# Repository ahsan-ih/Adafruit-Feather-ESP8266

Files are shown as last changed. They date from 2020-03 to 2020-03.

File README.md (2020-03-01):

## Adafruit Feather HUZZAH with ESP8266 - Loose Headers PCB

**DISCLAIMER:**: The original creators of the Adafruit Feather HUZZAH with ESP8266 are [Adafruit.com](https://www.adafruit.com). The development has been presented in the given repository just for demonstration purposes.

PCB files for the Adafruit Feather HUZZAH with ESP8266 - Loose Headers. Format is EagleCAD schematic and board layout

- https://www.adafruit.com/product/2821

### Description

Feather is the new development board from Adafruit, and like its namesake it is thin, light, and lets you fly! We designed Feather to be a new standard for portable microcontroller cores.

This is the **Adafruit Feather HUZZAH ESP8266** - our take on an 'all-in-one' ESP8266 WiFi development board with built in USB and battery charging. Its an ESP8266 WiFi module with all the extras you need, ready to rock! [We have other boards in the Feather family, check'em out here.](https://www.adafruit.com/feather)

At the Feather HUZZAH's heart is an ESP8266 WiFi microcontroller clocked at 80 MHz and at 3.3V logic. This microcontroller contains a Tensilica chip core as well as a full WiFi stack. You can program the microcontroller using the Arduino IDE for an easy-to-run Internet of Things core. We wired up a high-quality SiLabs CP2104 USB-Serial chip that can upload code at a blistering 921600 baud for fast development time. It also has auto-reset so no noodling with pins and reset button pressings. The CP2104 has better driver support than the CH340 and can do very high speeds without stability issues.

To make it easy to use for portable projects, we added a connector for any of our 3.7V Lithium polymer batteries and built in battery charging. You don't need a battery, it will run just fine straight from the micro USB connector. But, if you do have a battery, you can take it on the go, then plug in the USB to recharge. The Feather will automatically switch over to USB power when its available.

**Here's some handy specs!**

- Measures 2.0" x 0.9" x 0.28" (51mm x 23mm x 8mm) without headers soldered in
- Light as a (large?) feather - 9.7 grams
- ESP8266 @ 80MHz with 3.3V logic/power
- 4MB of FLASH (32 MBit)
- Built in WiFi 802.11 b/g/n
- 3.3V regulator with 500mA peak current output
- CP2104 USB-Serial converter onboard with 921600 max baudrate for speedy uploading
- Auto-reset support for getting into bootload mode before firmware upload
- 9 x GPIO pins - can also be used as I2C and SPI
- 1 x analog inputs 1.0V max
- Built in 100mA LiPoly charger with charging status indicator LED, can also cut a trace to disable the charger
- Pin #0 red LED for general purpose blinking. Pin #2 blue LED for bootloading debug & general purpose blinking
- Power/enable pin
- 4 mounting holes
- Reset button
  Comes fully assembled and tested, with a USB interface that lets you quickly use it with the Arduino IDE or NodeMCU Lua (it comes preprogrammed with the Lua interpreter). We also toss in some headers so you can solder it in and plug into a solderless breadboard. **Lipoly battery and USB cable not included** (but we do have lots of options in the shop if you'd like!)

[Check out our tutorial for all sorts of details, including schematics, files, IDE instructions, power management and more!](https://learn.adafruit.com/adafruit-feather-huzzah-esp8266)

### License

Adafruit invests time and resources providing this open source design, please support Adafruit and open-source hardware by purchasing products from [Adafruit](https://www.adafruit.com)!

Designed by Limor Fried/Ladyada for Adafruit Industries.

Creative Commons Attribution/Share-Alike, all text above must be included in any redistribution. See license.txt for additional details.

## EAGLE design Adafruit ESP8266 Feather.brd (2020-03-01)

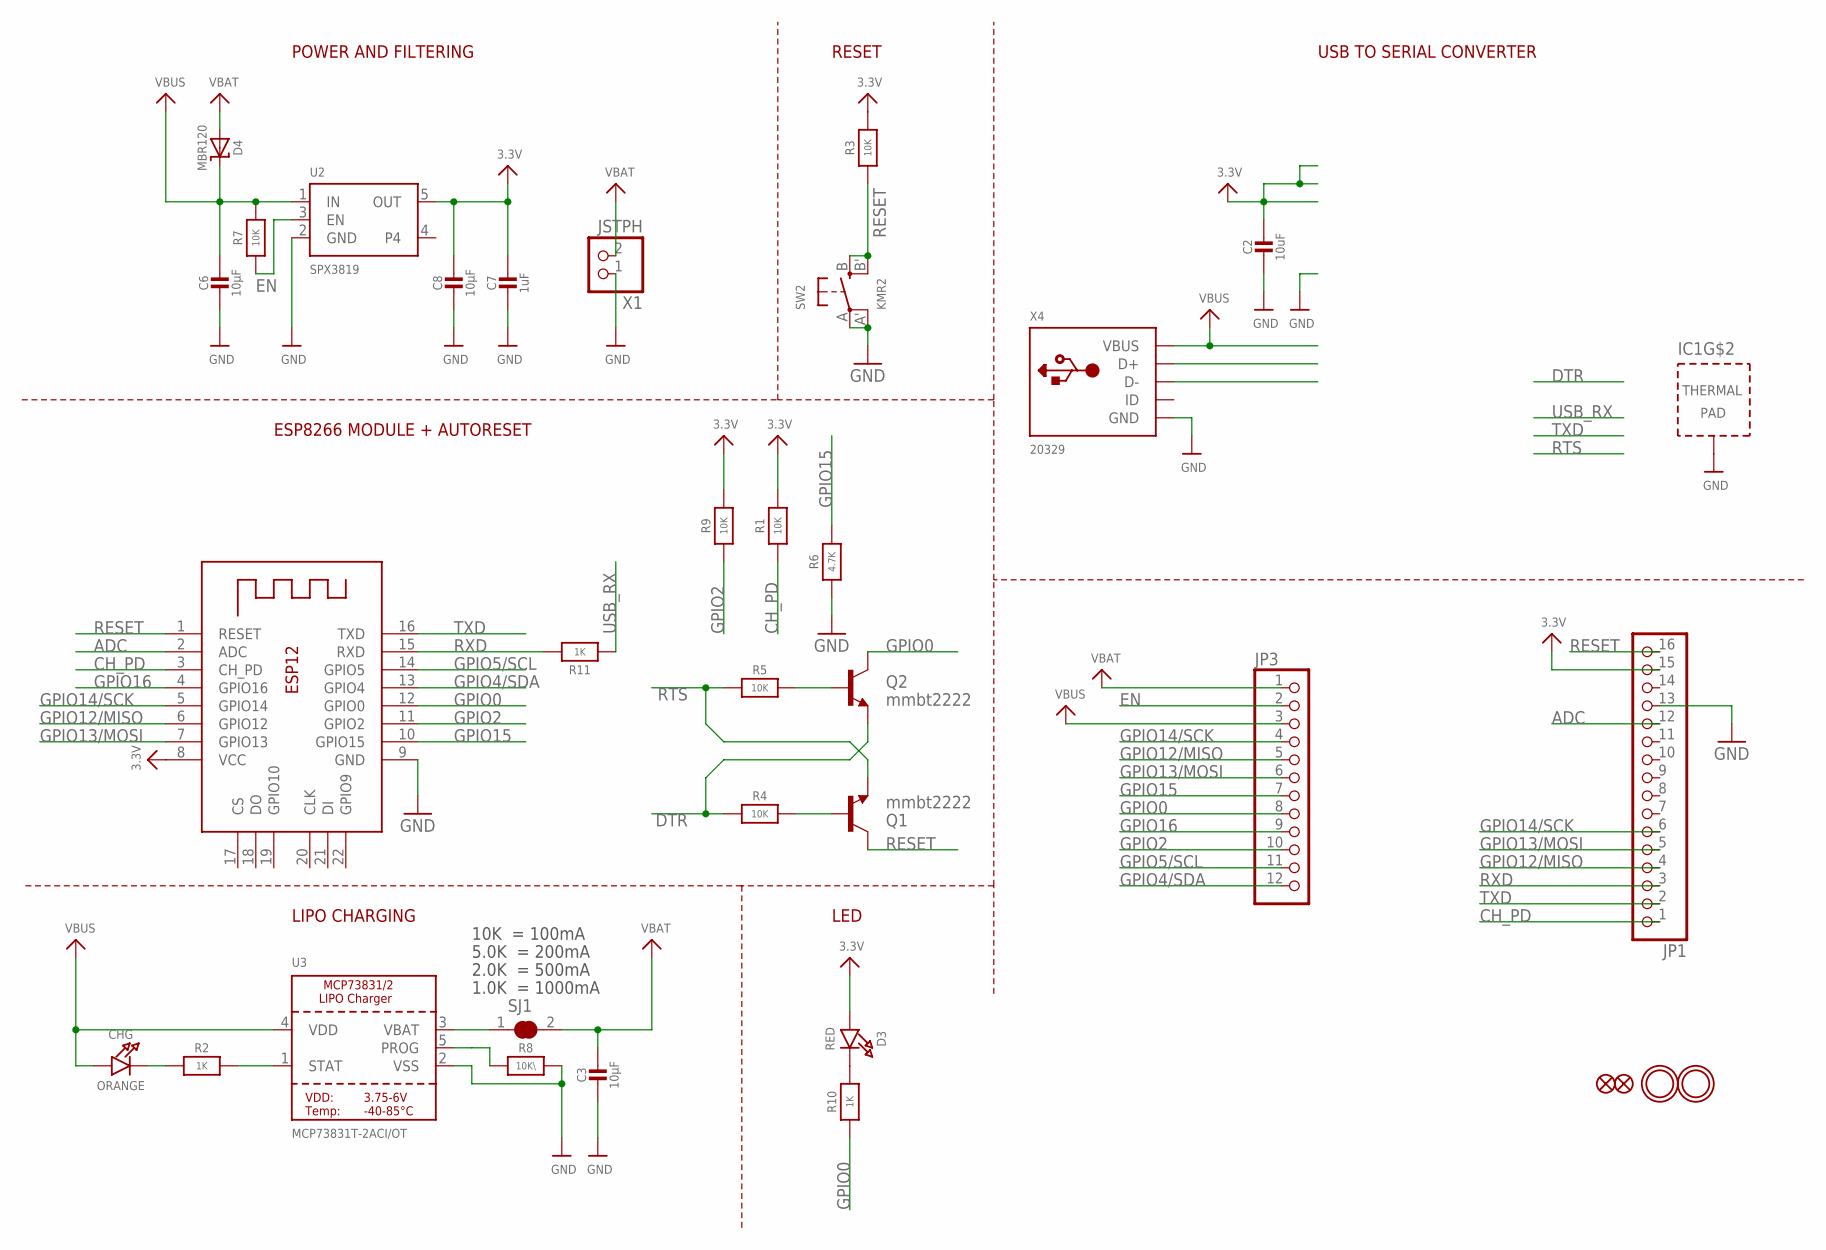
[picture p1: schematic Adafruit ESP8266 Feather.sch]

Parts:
C2: 10uF; 0805-NO
C3, C6, C8: 10µF; 0805-NO
C7: 1uF; 0603-NO
CHG: ORANGE; CHIPLED_0805_NOOUTLINE
D3: RED; CHIPLED_0805_NOOUTLINE
D4: MBR120; SOD-123
IC1: CP2104; QFN24_4MM_SMSC
JP1: HEADER-1X16ROUND; 1X16_ROUND
JP3: HEADER-1X12; 1X12_ROUND
Q1, Q2: mmbt2222; SOT23-3
R1, R3, R4, R7, R9: 10K; 0603-NO
R2, R10: 1K; 0603-NO
R5: 10K; _0603MP
R6: 4.7K; 0603-NO
R8: 10K\; 0603-NO
R11: 1K; _0603MP
SJ1: SOLDERJUMPER_CLOSED; SOLDERJUMPER_CLOSEDWIRE
SW2: KMR2; BTN_KMR2_4.6X2.8
U2: SPX3819; SOT23-5
U3: MCP73831T-2ACI/OT; SOT23-5
U$31, U$32: MOUNTINGHOLE2.5; MOUNTINGHOLE_2.5_PLATED
U$34, U$35: FIDUCIAL""; FIDUCIAL_1MM
X1: JSTPH; JSTPH2
X2: ESP-12; ESP-12E
X4: 20329; 4UCONN_20329_V2

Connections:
3.3V: C2.1, C7.1, C8.1, D3.A, JP1.15, R1.2, R3.2, R9.2, U2.5 (OUT), X2.8 (VCC)
ADC: JP1.12, X2.2 (ADC)
CH_PD: JP1.1, R1.1, X2.3 (CH_PD)
DTR: Q2.2 (E), R4.1
EN: JP3.2, R7.1, U2.3 (EN)
GND: C2.2, C3.2, C6.2, C7.2, C8.2, IC1.THERM (TP), JP1.13, R6.1, R8.2, SW2.A, SW2.A' (P1), U2.2 (GND), U3.2 (VSS), X1.1, X2.9 (GND), X4.BASE@1 (GND), X4.BASE@2 (GND), X4.GND, X4.SPRT@1 (GND), X4.SPRT@2 (GND), X4.SPRT@3 (GND), X4.SPRT@4 (GND)
GPIO0: JP3.8, Q2.3 (C), R10.1, X2.12 (GPIO0)
GPIO2: JP3.10, R9.1, X2.11 (GPIO2)
GPIO4/SDA: JP3.12, X2.13 (GPIO4)
GPIO5/SCL: JP3.11, X2.14 (GPIO5)
GPIO12/MISO: JP1.4, JP3.5, X2.6 (GPIO12)
GPIO13/MOSI: JP1.5, JP3.6, X2.7 (GPIO13)
GPIO14/SCK: JP1.6, JP3.4, X2.5 (GPIO14)
GPIO15: JP3.7, R6.2, X2.10 (GPIO15)
GPIO16: JP3.9, X2.4 (GPIO16)
unnamed: CHG.C, R2.1
unnamed: R2.2, U3.1 (STAT)
unnamed: R8.1, U3.5 (PROG)
unnamed: D3.C, R10.2
unnamed: SJ1.1, U3.3 (VBAT)
unnamed: Q1.1 (B), R4.2
unnamed: Q2.1 (B), R5.2
RESET: JP1.16, Q1.3 (C), R3.1, SW2.B (S), SW2.B' (S1), X2.1 (RESET)
RTS: Q1.2 (E), R5.1
RXD: JP1.3, R11.2, X2.15 (RXD)
TXD: JP1.2, X2.16 (TXD)
USB_RX: R11.1
VBAT: C3.1, D4.A, JP3.1, SJ1.2, X1.2
VBUS: C6.1, CHG.A, D4.C, JP3.3, R7.2, U2.1 (IN), U3.4 (VDD), X4.VBUS

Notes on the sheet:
POWER AND FILTERING
RESET
10K = 100mA
5.0K = 200mA
2.0K = 500mA
1.0K = 1000mA
USB TO SERIAL CONVERTER
LIPO CHARGING
LED
ESP8266 MODULE + AUTORESET

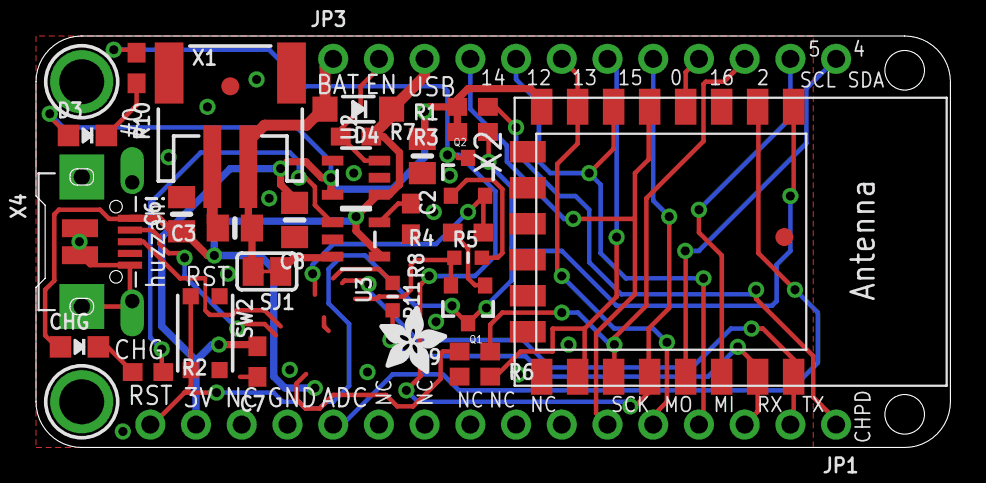
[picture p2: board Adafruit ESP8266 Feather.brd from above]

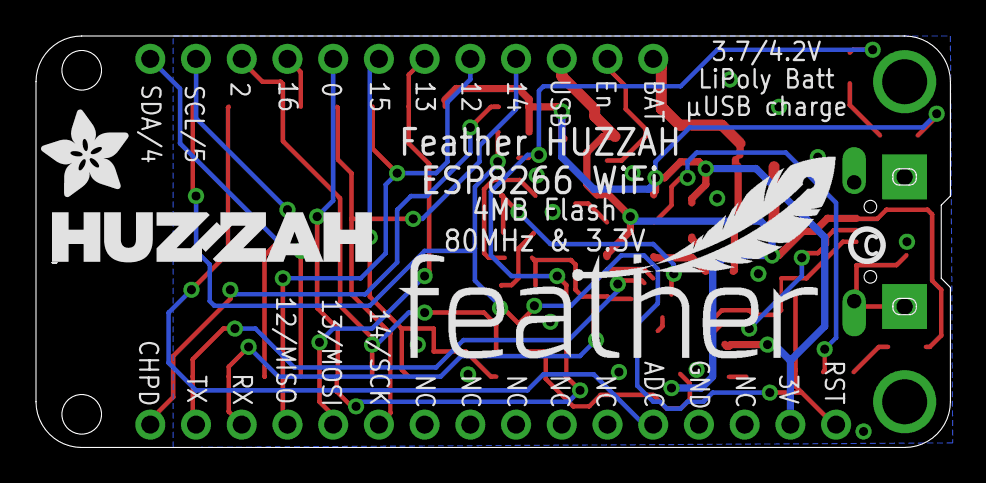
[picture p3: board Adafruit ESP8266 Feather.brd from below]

Board: 2 copper layers, 50.8 x 22.9 mm, 39 parts (4 on the bottom side), 28 nets.

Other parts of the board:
U$7: ADAFRUIT_5MM
U$9: FEATHERLOGO
U$13: PCBFEAT-REV-040
U$15: ADAFRUIT_3.5MM
U$23: HUZZAHLOGO

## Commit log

2020-03-01 Added components to the schematic & placed footprints in board layout
    [Adafruit ESP8266 Feather.brd, Adafruit ESP8266 Feather.sch]
2020-03-01 Finished Schematic: CP2104 + SPX3819 + MCP73831T-2ACI/OT + KMR2(Reset)
    [Adafruit ESP8266 Feather.brd, Adafruit ESP8266 Feather.sch]
2020-03-01 Schematic: ESP8266 + (JP1 + JP3 I/O Headers)
    [Adafruit ESP8266 Feather.brd, Adafruit ESP8266 Feather.sch]
2020-03-01 Traces Top: ESP8266 Unrouted
    [Adafruit ESP8266 Feather.brd, Adafruit ESP8266 Feather.sch]
2020-03-01 Feather .Brd: minor adjustments
    [Adafruit ESP8266 Feather.brd]
2020-03-01 Feather .Brd: completed the layout design
    [Adafruit ESP8266 Feather.brd, Adafruit ESP8266 Feather.sch]

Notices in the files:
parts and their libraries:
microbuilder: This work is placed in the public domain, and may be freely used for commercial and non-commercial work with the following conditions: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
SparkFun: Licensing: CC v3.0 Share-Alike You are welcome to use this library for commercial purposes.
